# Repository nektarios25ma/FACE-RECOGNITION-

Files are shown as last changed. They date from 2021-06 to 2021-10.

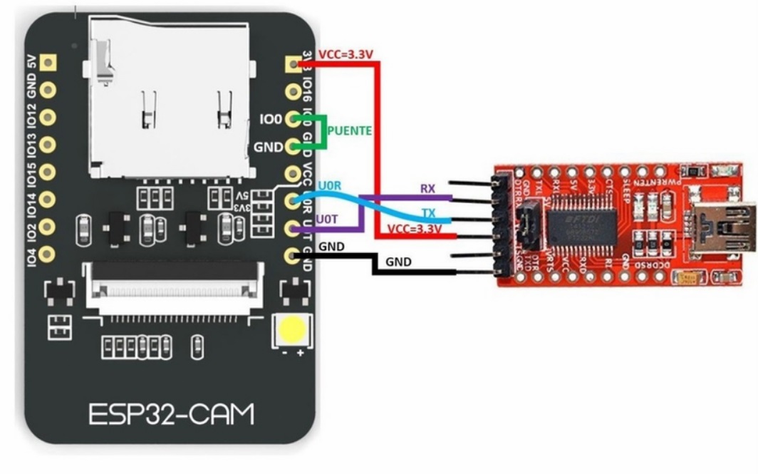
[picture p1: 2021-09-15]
ESP32 CAM PROGRAMMING CIRCUIT.jpg

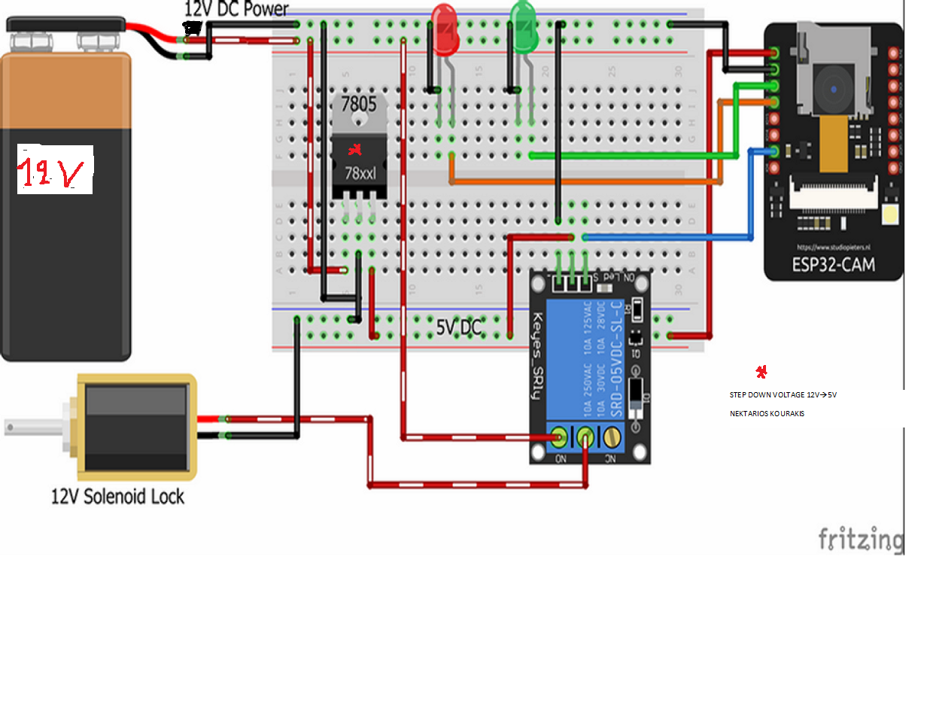
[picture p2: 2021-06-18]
CIRCUITconnections.png

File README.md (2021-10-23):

# FACE-RECOGNITION-
ΑΝΑΓΝΩΡΙΣΗ ΠΡΟΣΩΠΟΥ ΜΕ ΑΠΟΜΑΚΡΥΣΜΕΝΟ ΕΛΕΓΧΟ ΚΑΙ ΤΕΧΝΟΛΟΓΙΑ Artificial Intelligence
ΟΜΑΔΑ:FACE  RECOGNITION
1o link video (Εξήγηση και 1η  δοκιμή): FACErecognitionVAMOS2021
https://www.youtube.com/watch?v=_v_IU8wW4oc

ΑΝΑΓΝΩΡΙΣΗ ΠΡΟΣΩΠΟΥ ΜΕ ΑΠΟΜΑΚΡΥΣΜΕΝΟ ΕΛΕΓΧΟ ΚΑΙ ΤΕΧΝΟΛΟΓΙΑ Artificial Intelligence
Η  AI-Thinker ESP32-CAM module  που αποτελεί το κύριο μέρος του hardware είναι μια πολύ μικρή μονάδα κάμερας με το τσιπ ESP32-S που κοστίζει μόνο 11 €. Χρησιμοποιήθηκε το ανοικτό λογισμικό arduino ide με τεχνολογία AI σε ένα «πακέτο» που αποτελεί το φθηνότερο στην αγορά για την επίτευξη ανάλογου εγχειρήματος.
ΥΛΙΚΑ
Για να φτιαχτεί αυτό το έργο χρειάζονται τα ακόλουθα στοιχεία:
ESP32-CAM: https://grobotronics.com/camera-module-based-on-esp32.html = €11.00
Προγραμματιστής FTDI: https://www.hellasdigital.gr/electronics/transceivers-and-communications/ft232rl-ftdi-serials-adapter-module-mini-port-for-arduino-usb-to-ttl-3.3v-5.5v/ = €3,70 
Jumper wires: https://www.hellasdigital.gr/electronics/prototyping/cables-pins/40pcs-f-f-dupont-wire-jumper-cables/   =€3.5
breadboard : https://grobotronics.com/breadboard-400-tie-point-white-half-size.html =2Χ€3.20=6.40€
κλειδαριά: https://www.hellasdigital.gr/smartliving/smartlocks/12v-solenoid-lock/ = €7,44
memory card: https://grobotronics.com/microsdhc-16gb-class-10-sandisk-ultra-sdsquar-sdsquar-016g-gn6ma.html  = €6.90
θήκη μπαταριών : https://grobotronics.com/3x18650-wire-leads.html = €1.50
μπαταρίες18650: https://grobotronics.com/battery-lithium-18650-3.6v-2600mah.html = 2Χ€4.80=€9.6
step down dc🡪dc: https://grobotronics.com/dc-dc-step-down-1.3-35v-3a.html = €2.90
ΨΥΚΤΡΑ: https://grobotronics.com/o-220-el.html  = €0.10

ΣΥΝΟΛΟ=52.94€

ΥΛΟΠΟΙΗΣΗ ΜΕ ΧΡΗΣΗ ΤΟΥ ΑΝΟΙΚΤΟΥ ΛΟΓΙΣΜΙΚΟΥ 

ΠΕΡΙΓΡΑΦΗ ΠΡΟΒΛΗΜΑΤΟΣ
Η ασφάλεια στον αυτοματισμό σπιτιού-εργασίας  με αναγνώριση προσώπου σε συνδυασμό με Internet Of Things  εφαρμογή για διαδικτυακή  προβολή είναι η πρόκληση που θέλαμε να αντιμετωπίσουμε.
Περιγραφή προτεινόμενης λύσης
Σε αυτό το έργο  χρησιμοποιήσαμε την ESP32 cam   για να προσθέσουμε ασφάλεια στον αυτοματισμό του σπιτιού-σχολείου-εργαστηρίου-τάξης όπως και διευκόλυνση ελέγχου π.χ. κλείδωμα –ξεκλείδωμα πόρτας ανάλογα το πρόσωπο-face recognition, καταγραφή προσώπων και αποστολή της εικόνας τους διαδικτυακά.
Επίσης σε αυτό το έργο  δημιουργήσαμε μια κάμερα παρακολούθησης  με την  κάμερα ESP32 όπου  δημιουργεί έναν διακομιστή διαδικτύου ροής βίντεο στον οποίο μπορείτε να αποκτήσετε πρόσβαση με οποιαδήποτε συσκευή στο δίκτυό σας.
ΚΟΙΝΩΝΙΚΟΣ ΑΝΤΙΚΤΥΠΟΣ
Μια από τις αυξανόμενες απαιτήσεις της εποχής μας είναι η ασφάλεια. Πόσο μάλλον όταν μια μαθητική κατασκευή STEM καταφέρνει μέσω Τ.Ν. την αναγνώριση προσώπου με τόσο μικρό κόστος. Ο θετικός αντίκτυπος της κατασκευής μας προκάλεσε την επιθυμία -παραγγελία ανάλογων συσκευών . Είναι ευχάριστο να φτιάχνουν τα μέλη της ομάδας(μαθητές) μια κατασκευή των 50 ευρώ (προσεγμένη) να πετυχαίνει αποτελέσματα τα  οποία στην τοπική αγορά αδυνατεί προς το παρόν να τα προσφέρει ιδιωτική εταιρεία. Εφαρμογή βρήκε άμεση στην ασφάλεια εργαστηρίου όπως και στις πανελλήνιες εξετάσεις που πραγματοποιούνται στο σχολείο μας(αυτόματο face control).   
ΠΕΡΙΓΡΑΦΗ ΟΜΑΔΑΣ
Ο προγραμματιστής και το θετικό μυαλό της ομάδας είναι ο Ζίλ. Η Ιωάννα της κατασκευής -συνδεσμολογίας. Είναι μαθητές της Ά λυκείου με μεράκι και αγάπη για το STEM.
 ΚΑΤΑΣΚΕΥΗ
Α.ΠΡΟΓΡΑΜΜΑΤΙΣΜΟΣ(upload code)
1ο βήμα: φτιάχνω το  κύκλωμα https://github.com/nektarios25ma/FACE-RECOGNITION-/blob/main/ESP32%20CAM%20PROGRAMMING%20CIRCUIT.jpg

 Προγραμματισμός της πλακέτας esp32 cam χρησιμοποιώντας FTDI σύμφωνα με το κύκλωμα:
TIP επιτυχίας στον προγραμματισμό της esp32 cam : η σύνδεση VCC 3.3V μερικές φορές αποτυγχάνει έτσι τότε μεταφέρω το jumper του FTDI απο τα 3.3 στα 5 VOLT και  το κόκκινο καλώδιο στα 5 V της esp32 cam.
2o βήμα :
Προσθήκη πλακέτας esp32
Δείτε τι πρέπει να κάνετε για να εγκαταστήσετε τους πίνακες ESP32 στο Arduino IDE:
 
 Ανοίξτε το Arduino IDE. Βεβαιωθείτε ότι βρίσκεστε στην έκδοση 1.8 ή νεότερη, αν όχι, ενημερώστε το IDE με την πιο πρόσφατη έκδοση.
 
Κάντε κλικ στο μενού Αρχείο στην επάνω γραμμή μενού.
 
Κάντε κλικ στο στοιχείο μενού Προτιμήσεις. Αυτό θα ανοίξει ένα παράθυρο διαλόγου Προτιμήσεις.
 
Αναζητήστε το πλαίσιο κειμένου με την ένδειξη "Επιπλέον URLs διαχειριστή πλακετών".
Εάν υπάρχει ήδη κείμενο σε αυτό το πλαίσιο, προσθέστε κώμα στο τέλος του και, στη συνέχεια, ακολουθήστε το επόμενο βήμα.
Επικολλήστε τον παρακάτω σύνδεσμο στο πλαίσιο κειμένου-https://raw.githubusercontent.com/espressif/arduino-esp32/gh-pages/package_esp32_index.json
Κάντε κλικ στο κουμπί OK για να αποθηκεύσετε τη ρύθμιση.
Ανοίξτε-πατήστε την επιλογή εργαλεία απο την πάνω μπάρα του arduino ide (αφού πρώτα ανοίξετε το πρόγραμμα)
Επιλέξτε πλακέτα και μετά διαχειρηστής πλακετών.
Γράφετε esp32 και επιλέγετε Esp32 (by espresif).
Πατάτε εγκατάσταση.
3ο βήμα:
Ανεβάστε το πρόγραμμα στην πλακέτα: https://github.com/nektarios25ma/FACE-RECOGNITION-:αφού κατεβάσετε όλο το φάκελο CameraFaceRecognitionDoorLock2 απο τον παραπάνω σύνδεσμο και ανοίξετε το CameraFaceRecognitionDoorLock2.ino.
ΔΙΑΒΑΣΤΕ ΤO ΣΧΟΛΙO ΣΤHN ΠΡΩΤH ΓΡΑΜΜH.
Μόλις ανέβει το πρόγραμμα ανοίγουμε το serial monitor και αντιγράφουμε την διεύθυνση http την οποία επικολλούμε στον browser του ταμπλετ ή smartphone . Την ανοίγω* όταν έχω ολοκληρώσει την παρακάτω κατασκευή και ανοίξω την τροφοδοσία.
 
Υ.Γ. Απο τα εργαλεία στο arduino ide διαλέξτε πλακέτα :AI Thinker ESP32-CAM
 
Β. Τελική κατασκευή:
Φτιάχνω το παρακάτω κύκλωμα
https://github.com/nektarios25ma/FACE-RECOGNITION-/blob/main/CIRCUITconnections.png
 
Στην θέση του 7805 voltage regulator μπορούμε να βάλουμε εναλλακτικά step down voltage.
Μόλις ενεργοποιήσω την συσκευή ανοίγω την http διεύθυνση που αναφέρω παραπάνω* και "πατάω " start stream και face recognition από όπου με το enroll face διαλέγω τα πρόσωπα -ποζάρουν στην κάμερα-που επιτρέπω να εισέλθουν στον χώρο. 
Τέλος …όχι θα λέγαμε.

Τα επόμενα βήματα είναι 3d εξαρτήματα για να φιλοξενήσουν την esp32 cam (θα τα βρείτε στο Git Hub)

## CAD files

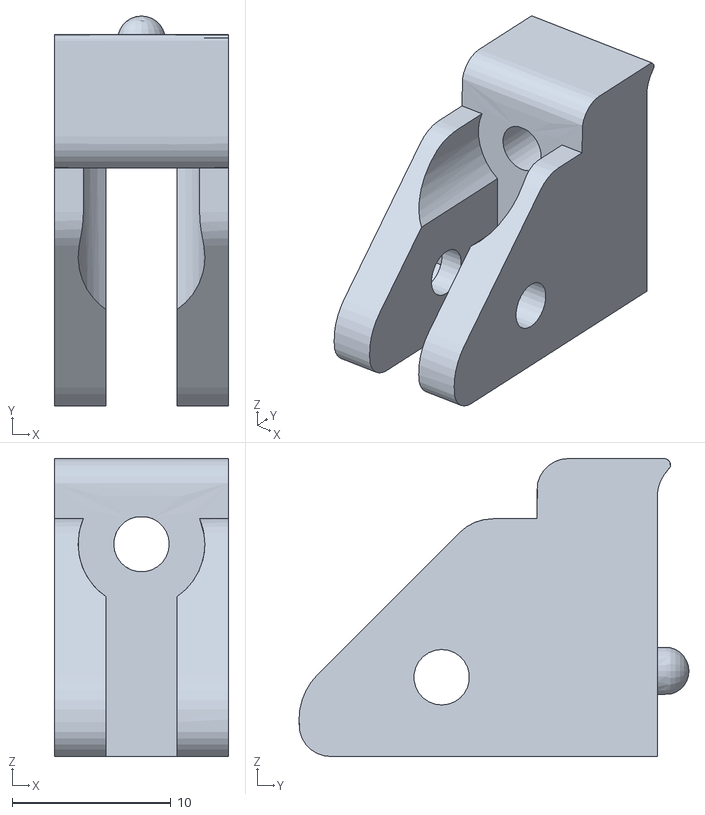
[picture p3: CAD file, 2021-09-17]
stl_esp32 cam/case_mount.stl
11.0 x 24.6 x 18.8

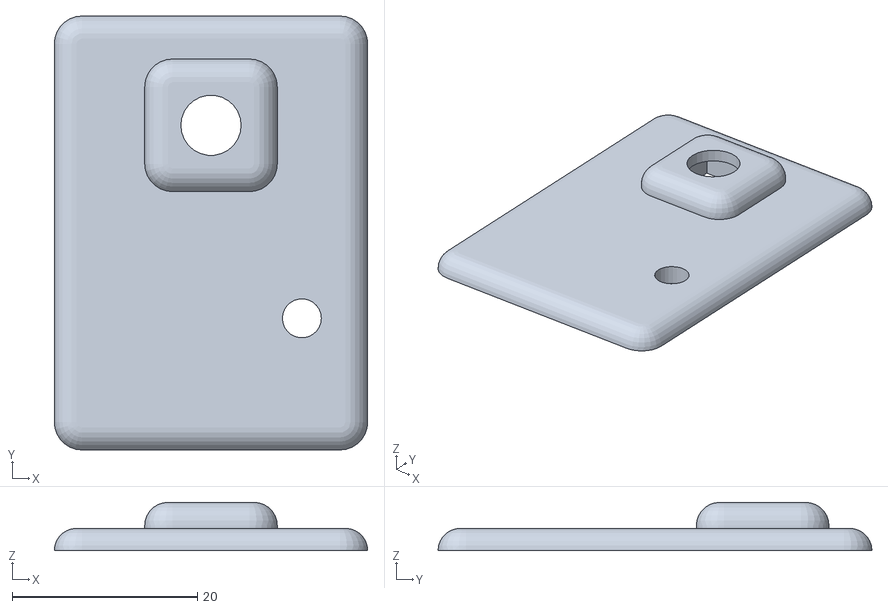
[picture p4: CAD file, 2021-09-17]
stl_esp32 cam/front_case_A.stl
33.8 x 46.8 x 5.20

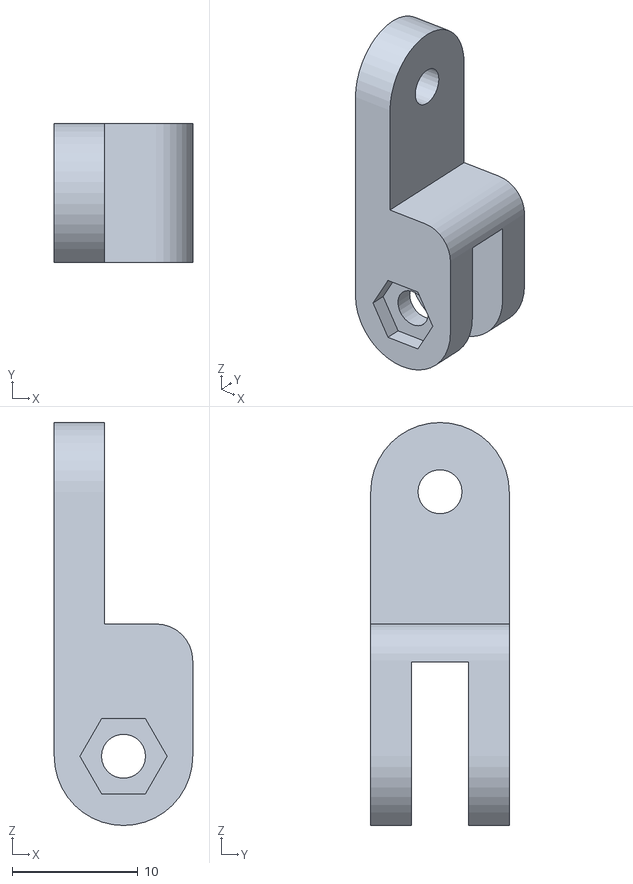
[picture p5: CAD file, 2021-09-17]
stl_esp32 cam/case_knuckle.stl
11.0 x 11.0 x 32.0

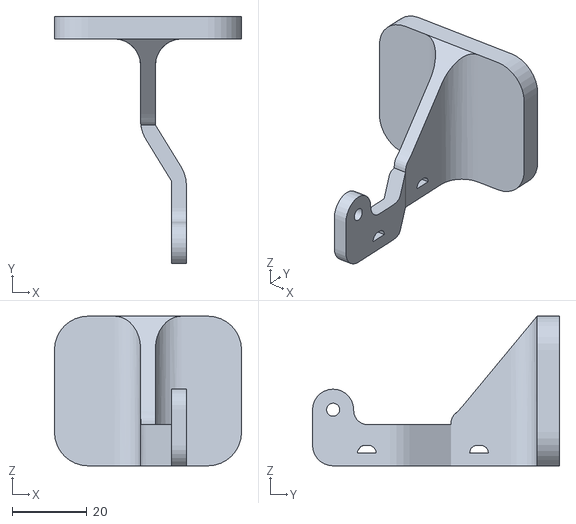
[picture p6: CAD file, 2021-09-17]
stl_esp32 cam/case_stand.stl
50.0 x 66.0 x 40.0

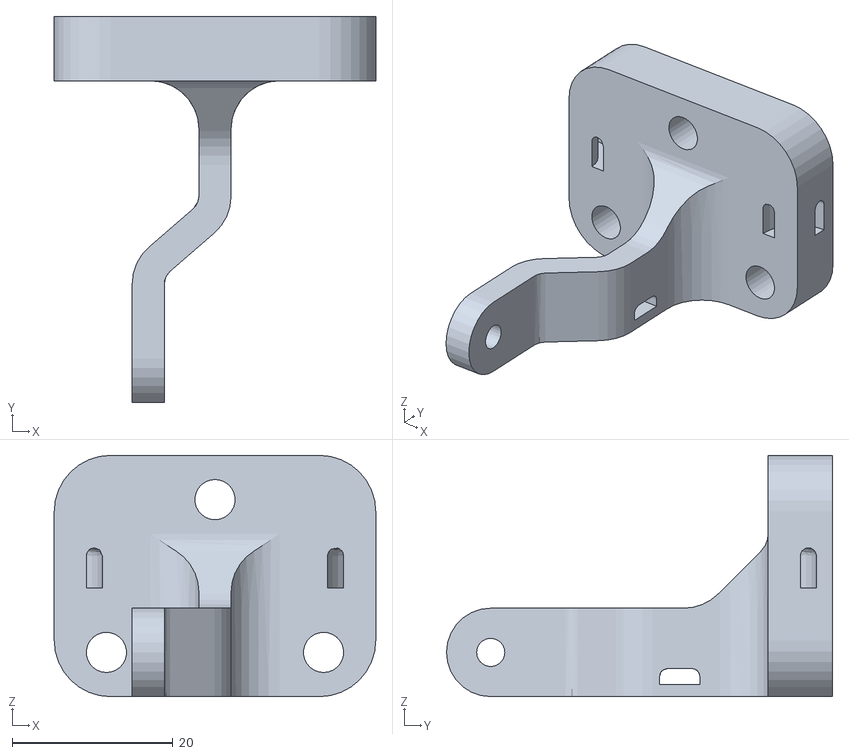
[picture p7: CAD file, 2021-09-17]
stl_esp32 cam/case_universal_mount.stl
40.0 x 48.0 x 30.0

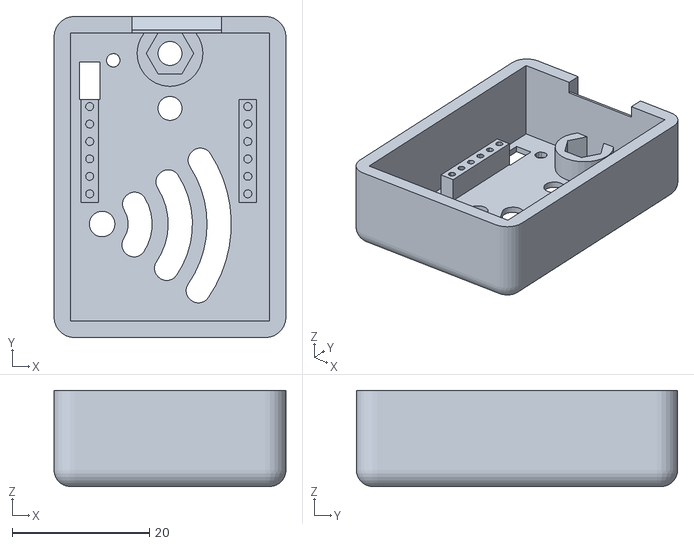
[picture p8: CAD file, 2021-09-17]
stl_esp32 cam/case_rear.stl
33.8 x 46.8 x 14.0

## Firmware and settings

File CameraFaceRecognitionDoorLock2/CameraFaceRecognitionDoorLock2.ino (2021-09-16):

//ΠΡΟΣΟΧΗ ΣΤΗΝ 22-23 ΓΡΑΜΜΗ ΒΑΛΤΕ ΤΟ ΔΙΚΟ ΣΑΣ ssid και password του δικτύου σας(με WIFI)
//ESP Camera Artificial Intelligence Face Detection Automatic Door Lock
#include "esp_camera.h"
#include <WiFi.h>

//
// WARNING!!! Make sure that you have either selected ESP32 Wrover Module,
//            or another board which has PSRAM enabled
//

// Select camera model
//#define CAMERA_MODEL_WROVER_KIT
//#define CAMERA_MODEL_ESP_EYE
//#define CAMERA_MODEL_M5STACK_PSRAM
//#define CAMERA_MODEL_M5STACK_WIDE
#define CAMERA_MODEL_AI_THINKER
#define Relay 2
#define Red 13
#define Green 12
#include "camera_pins.h"

const char* ssid = "COSMOTE-F92499"; //Wifi Name SSID
const char* password = "2821047809aris"; //WIFI Password

void startCameraServer();

boolean matchFace = false;
boolean activateRelay = false;
long prevMillis=0;
int interval = 5000;

void setup() {
  pinMode(Relay,OUTPUT);
  pinMode(Red,OUTPUT);
  pinMode(Green,OUTPUT);
  digitalWrite(Relay,HIGH);
  digitalWrite(Red,HIGH);
  digitalWrite(Green,LOW);
  
  Serial.begin(115200);
  Serial.setDebugOutput(true);
  Serial.println();

  camera_config_t config;
  config.ledc_channel = LEDC_CHANNEL_0;
  config.ledc_timer = LEDC_TIMER_0;
  config.pin_d0 = Y2_GPIO_NUM;
  config.pin_d1 = Y3_GPIO_NUM;
  config.pin_d2 = Y4_GPIO_NUM;
  config.pin_d3 = Y5_GPIO_NUM;
  config.pin_d4 = Y6_GPIO_NUM;
  config.pin_d5 = Y7_GPIO_NUM;
  config.pin_d6 = Y8_GPIO_NUM;
  config.pin_d7 = Y9_GPIO_NUM;
  config.pin_xclk = XCLK_GPIO_NUM;
  config.pin_pclk = PCLK_GPIO_NUM;
  config.pin_vsync = VSYNC_GPIO_NUM;
  config.pin_href = HREF_GPIO_NUM;
  config.pin_sscb_sda = SIOD_GPIO_NUM;
  config.pin_sscb_scl = SIOC_GPIO_NUM;
  config.pin_pwdn = PWDN_GPIO_NUM;
  config.pin_reset = RESET_GPIO_NUM;
  config.xclk_freq_hz = 20000000;
  config.pixel_format = PIXFORMAT_JPEG;
  //init with high specs to pre-allocate larger buffers
  if(psramFound()){
    config.frame_size = FRAMESIZE_UXGA;
    config.jpeg_quality = 10;
    config.fb_count = 2;
  } else {
    config.frame_size = FRAMESIZE_SVGA;
    config.jpeg_quality = 12;
    config.fb_count = 1;
  }

#if defined(CAMERA_MODEL_ESP_EYE)
  pinMode(13, INPUT_PULLUP);
  pinMode(14, INPUT_PULLUP);
#endif

  // camera init
  esp_err_t err = esp_camera_init(&config);
  if (err != ESP_OK) {
    Serial.printf("Camera init failed with error 0x%x", err);
    return;
  }

  sensor_t * s = esp_camera_sensor_get();
  //initial sensors are flipped vertically and colors are a bit saturated
  if (s->id.PID == OV3660_PID) {
    s->set_vflip(s, 1);//flip it back
    s->set_brightness(s, 1);//up the blightness just a bit
    s->set_saturation(s, -2);//lower the saturation
  }
  //drop down frame size for higher initial frame rate
  s->set_framesize(s, FRAMESIZE_QVGA);

#if defined(CAMERA_MODEL_M5STACK_WIDE)
  s->set_vflip(s, 1);
  s->set_hmirror(s, 1);
#endif

  WiFi.begin(ssid, password);

  while (WiFi.status() != WL_CONNECTED) {
    delay(500);
    Serial.print(".");
  }
  Serial.println("");
  Serial.println("WiFi connected");

  startCameraServer();

  Serial.print("Camera Ready! Use 'http://");
  Serial.print(WiFi.localIP());
  Serial.println("' to connect");
}

void loop() {
  if(matchFace==true && activateRelay==false)
  {
    activateRelay=true;
    digitalWrite(Relay,LOW);
    digitalWrite(Green,HIGH);
    digitalWrite(Red,LOW);
    prevMillis=millis();
    }
    if (activateRelay == true && millis()-prevMillis > interval)
    {
      activateRelay=false;
      matchFace=false;
      digitalWrite(Relay,HIGH);
      digitalWrite(Green,LOW);
      digitalWrite(Red,HIGH);
      }
}

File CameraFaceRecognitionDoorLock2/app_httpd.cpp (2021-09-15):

// Copyright 2015-2016 Espressif Systems (Shanghai) PTE LTD
//
// Licensed under the Apache License, Version 2.0 (the "License");
// you may not use this file except in compliance with the License.
// You may obtain a copy of the License at
//
//     http://www.apache.org/licenses/LICENSE-2.0
//
// Unless required by applicable law or agreed to in writing, software
// distributed under the License is distributed on an "AS IS" BASIS,
// WITHOUT WARRANTIES OR CONDITIONS OF ANY KIND, either express or implied.
// See the License for the specific language governing permissions and
// limitations under the License.
#include "esp_http_server.h"
#include "esp_timer.h"
#include "esp_camera.h"
#include "img_converters.h"
#include "camera_index.h"
#include "Arduino.h"

#include "fb_gfx.h"
#include "fd_forward.h"
#include "fr_forward.h"

#define ENROLL_CONFIRM_TIMES 5
#define FACE_ID_SAVE_NUMBER 7

#define FACE_COLOR_WHITE  0x00FFFFFF
#define FACE_COLOR_BLACK  0x00000000
#define FACE_COLOR_RED    0x000000FF
#define FACE_COLOR_GREEN  0x0000FF00
#define FACE_COLOR_BLUE   0x00FF0000
#define FACE_COLOR_YELLOW (FACE_COLOR_RED | FACE_COLOR_GREEN)
#define FACE_COLOR_CYAN   (FACE_COLOR_BLUE | FACE_COLOR_GREEN)
#define FACE_COLOR_PURPLE (FACE_COLOR_BLUE | FACE_COLOR_RED)

typedef struct {
        size_t size; //number of values used for filtering
        size_t index; //current value index
        size_t count; //value count
        int sum;
        int * values; //array to be filled with values
} ra_filter_t;

typedef struct {
        httpd_req_t *req;
        size_t len;
} jpg_chunking_t;

#define PART_BOUNDARY "123456789000000000000987654321"
static const char* _STREAM_CONTENT_TYPE = "multipart/x-mixed-replace;boundary=" PART_BOUNDARY;
static const char* _STREAM_BOUNDARY = "\r\n--" PART_BOUNDARY "\r\n";
static const char* _STREAM_PART = "Content-Type: image/jpeg\r\nContent-Length: %u\r\n\r\n";

static ra_filter_t ra_filter;
httpd_handle_t stream_httpd = NULL;
httpd_handle_t camera_httpd = NULL;

static mtmn_config_t mtmn_config = {0};
static int8_t detection_enabled = 0;
static int8_t recognition_enabled = 0;
static int8_t is_enrolling = 0;
static face_id_list id_list = {0};

extern boolean matchFace;

static ra_filter_t * ra_filter_init(ra_filter_t * filter, size_t sample_size){
    memset(filter, 0, sizeof(ra_filter_t));

    filter->values = (int *)malloc(sample_size * sizeof(int));
    if(!filter->values){
        return NULL;
    }
    memset(filter->values, 0, sample_size * sizeof(int));

    filter->size = sample_size;
    return filter;
}

static int ra_filter_run(ra_filter_t * filter, int value){
    if(!filter->values){
        return value;
    }
    filter->sum -= filter->values[filter->index];
    filter->values[filter->index] = value;
    filter->sum += filter->values[filter->index];
    filter->index++;
    filter->index = filter->index % filter->size;
    if (filter->count < filter->size) {
        filter->count++;
    }
    return filter->sum / filter->count;
}

static void rgb_print(dl_matrix3du_t *image_matrix, uint32_t color, const char * str){
    fb_data_t fb;
    fb.width = image_matrix->w;
    fb.height = image_matrix->h;
    fb.data = image_matrix->item;
    fb.bytes_per_pixel = 3;
    fb.format = FB_BGR888;
    fb_gfx_print(&fb, (fb.width - (strlen(str) * 14)) / 2, 10, color, str);
}

static int rgb_printf(dl_matrix3du_t *image_matrix, uint32_t color, const char *format, ...){
    char loc_buf[64];
    char * temp = loc_buf;
    int len;
    va_list arg;
    va_list copy;
    va_start(arg, format);
    va_copy(copy, arg);
    len = vsnprintf(loc_buf, sizeof(loc_buf), format, arg);
    va_end(copy);
    if(len >= sizeof(loc_buf)){
        temp = (char*)malloc(len+1);
        if(temp == NULL) {
            return 0;
        }
    }
    vsnprintf(temp, len+1, format, arg);
    va_end(arg);
    rgb_print(image_matrix, color, temp);
    if(len > 64){
        free(temp);
    }
    return len;
}

static void draw_face_boxes(dl_matrix3du_t *image_matrix, box_array_t *boxes, int face_id){
    int x, y, w, h, i;
    uint32_t color = FACE_COLOR_YELLOW;
    if(face_id < 0){
        color = FACE_COLOR_RED;
    } else if(face_id > 0){
        color = FACE_COLOR_GREEN;
    }
    fb_data_t fb;
    fb.width = image_matrix->w;
    fb.height = image_matrix->h;
    fb.data = image_matrix->item;
    fb.bytes_per_pixel = 3;
    fb.format = FB_BGR888;
    for (i = 0; i < boxes->len; i++){
        // rectangle box
        x = (int)boxes->box[i].box_p[0];
        y = (int)boxes->box[i].box_p[1];
        w = (int)boxes->box[i].box_p[2] - x + 1;
        h = (int)boxes->box[i].box_p[3] - y + 1;
        fb_gfx_drawFastHLine(&fb, x, y, w, color);
        fb_gfx_drawFastHLine(&fb, x, y+h-1, w, color);
        fb_gfx_drawFastVLine(&fb, x, y, h, color);
        fb_gfx_drawFastVLine(&fb, x+w-1, y, h, color);
#if 0
        // landmark
        int x0, y0, j;
        for (j = 0; j < 10; j+=2) {
            x0 = (int)boxes->landmark[i].landmark_p[j];
            y0 = (int)boxes->landmark[i].landmark_p[j+1];
            fb_gfx_fillRect(&fb, x0, y0, 3, 3, color);
        }
#endif
    }
}

static int run_face_recognition(dl_matrix3du_t *image_matrix, box_array_t *net_boxes){
    dl_matrix3du_t *aligned_face = NULL;
    int matched_id = 0;

    aligned_face = dl_matrix3du_alloc(1, FACE_WIDTH, FACE_HEIGHT, 3);
    if(!aligned_face){
        Serial.println("Could not allocate face recognition buffer");
        return matched_id;
    }
    if (align_face(net_boxes, image_matrix, aligned_face) == ESP_OK){
        if (is_enrolling == 1){
            int8_t left_sample_face = enroll_face(&id_list, aligned_face);

            if(left_sample_face == (ENROLL_CONFIRM_TIMES - 1)){
                Serial.printf("Enrolling Face ID: %d\n", id_list.tail);
            }
            Serial.printf("Enrolling Face ID: %d sample %d\n", id_list.tail, ENROLL_CONFIRM_TIMES - left_sample_face);
            rgb_printf(image_matrix, FACE_COLOR_CYAN, "ID[%u] Sample[%u]", id_list.tail, ENROLL_CONFIRM_TIMES - left_sample_face);
            if (left_sample_face == 0){
                is_enrolling = 0;
                Serial.printf("Enrolled Face ID: %d\n", id_list.tail);
            }
        } else {
            matched_id = recognize_face(&id_list, aligned_face);
            if (matched_id >= 0) {
                Serial.printf("Match Face ID: %u\n", matched_id);
                rgb_printf(image_matrix, FACE_COLOR_GREEN, "Hello Friend %u", matched_id);

                matchFace=true;
            } else {
                Serial.println("No Match Found");
                rgb_print(image_matrix, FACE_COLOR_RED, "Intruder Alert!");
                matched_id = -1;
            }
        }
    } else {
        Serial.println("Face Not Aligned");
        //rgb_print(image_matrix, FACE_COLOR_YELLOW, "Human Detected");
    }

    dl_matrix3du_free(aligned_face);
    return matched_id;
}
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
